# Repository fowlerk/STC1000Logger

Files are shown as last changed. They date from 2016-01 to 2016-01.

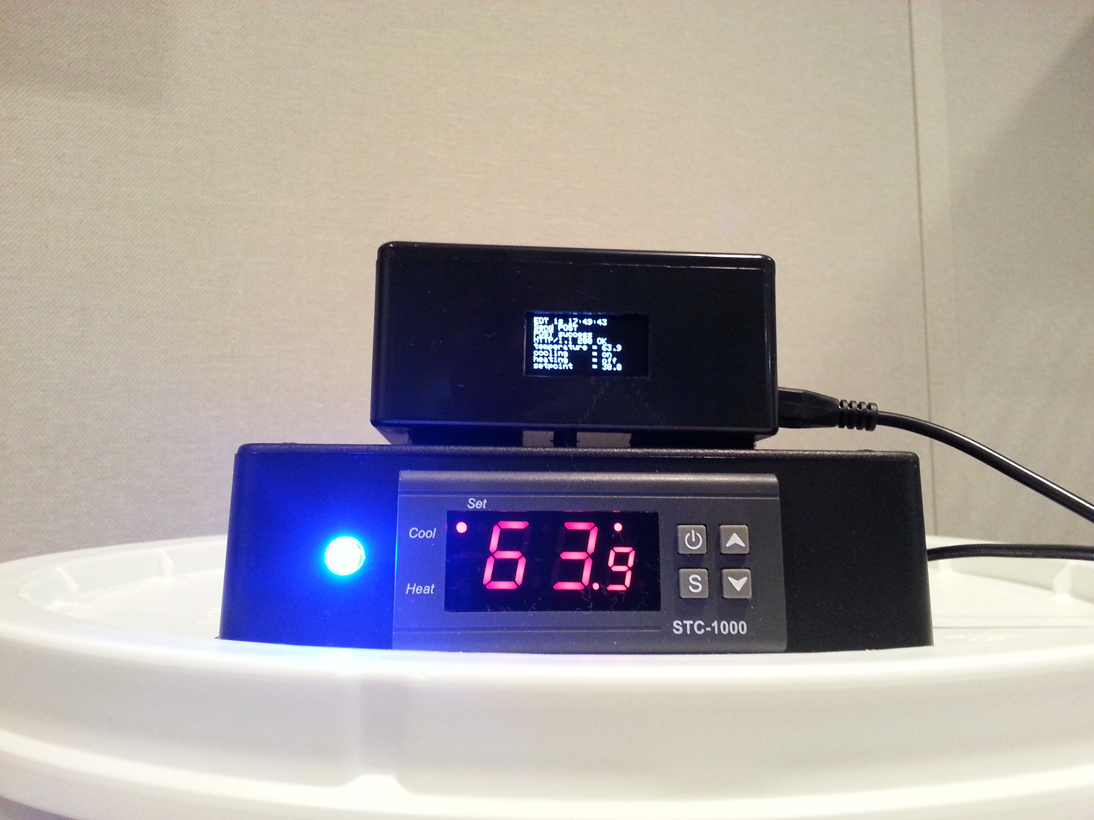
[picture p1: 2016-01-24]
20160124_175003.jpg

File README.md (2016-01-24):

##STC-1000+ Wireless Data Logger

This project creates a wireless data logger to interface with the STC-1000+ dual-stage temperature controller, running the (great!) communications firmware designed and written by Mats Staffansson.  Let me take the opportunity to thank Mats for all of his great contributions to the homebrewing community through his tireless efforts in creating the various versions of the STC firmware.  Without him, none of this would have been possible.

This code retrieves key data from the STC-1000 on a periodic basis as defined in the code.  The parameters retrieved and logged are:  setpoint, current probe temperature, status of the cooling and heating relays, run-mode (profile or thermostat), step (for profile), and duration hours.

This version of the project was written specifically for the Adafruit Huzzah ESP-8266 package.  Through the various iterations of this effort, I've used other versions of the ESP (notably the Cactus Micro version initially), but settled on this one because of its stability, breakout of most of the GPIO pins, and huge (4M) flash size.  This has allowed be to include support for much more extensive error-checking and correction in the code, along with support for an external display (an SSD1306 based OLED) to monitor what’s going on in real time.

## Background

Being a homebrewer for several years now, I initially became interested in temperature control for my fermentations when I wanted to tackle my first lager.  I stumbled on Mats thread on the STC, and was impressed with what he'd done.  After purchasing and using a controller with his firmware a couple of times, I wanted to be able to log my fermentation activity in order to help improve my future attempts.  Mats inspired me in some of his discussions on using the ESP in order to do this, though I eventually decided to take a somewhat different route than the base ESP-01 using Sming he’d mentioned.  I ran across the Cactus Micro package from April Brother and decided to use it for my first attempt.  It combines the Atmel ATmega32U4 MCU and the ESP-8266 WiFi SOC.  Though I managed to put together a version that ran (fairly) well on this package, I found it somewhat unreliable in that it would hang every few days to hours.  A simple restart would get it running again, but I was frustrated by not knowing what was going on in real time, and more so, by not having enough flash to be able to add what I considered to be adequate error checking and correction to the code.  (This may have been as much a reflection of my barely-adequate coding or electronics abilities, but I tire quickly of trying to optimize code to fit in smaller flash.)

So, I began looking around for better hardware solutions that were still relatively inexpensive.  I decided to try the Adafruit Huzzah ESP-8266 as an alternative.  It didn't take long to fall in love with this package.  It seems to be much more stable, has tons of flash (4M), breaks out all of the GPIO’s for use, and supports nice additions like h/w SPI (used for the OLED display).

## Getting it Running

### The Data Stream

Though there are a number of free data-streaming services available on-line, I decided to first try one provided by SparkFun at data.sparkfun.com.  It is a public implementation of a Phant server, though the code is freely available to download and run your own instance if you desire.  For my initial attempt, I didn't mind putting this up so that it was available to the public, but was very interested in being able to run my own instance in the future.  In order to get started, you must first go to data.sparkfun.com and set up a data stream for logging your data.  It is quite simple and fast to do so, just be sure to create fieldnames that match exactly the names used in the code.  Also be sure to note the public and private keys, as these must be entered in the code to connect to the stream once created.

### The OLED Library

One of the downsides for working with the ESP-8266 is that some of the libraries still have not been ported to this platform for the Arduino IDE (which is what I used for my efforts).  When I decided to use the SSD1306 controller-based OLED, I found this to be a minor stumbling block initially, but eventually discovered someone had been able to make minor edits to the Adafruit library to support this.  It essentially amounts to a couple of trivial edits (additions) to one of the library files (Adafruit_GFX.cpp), and is described here:  [https://github.com/somhi/ESP_SSD1306](https://github.com/somhi/ESP_SSD1306)

I saved the edits to a copy of the original library called ESP_SSD1306 so that I could use either the original or the modified one going forward.  (Thanks to SOMHI for his efforts on this, and Adafruit / LadyAda for their work in creating the original library!)

Note that I used a 4-wire SPI version of the OLED, though I've read others have gotten the I2C version working as well.  I’ve used both 1.3 inch and 0.96 inch versions of these successfully.

Final note on the OLED...I added this strictly to have a local display of what was happening throughout the logging process as a realtime monitor.  It is strictly optional and the logger will work fine without this connected (though you'll be a little blind about what’s going on unless you have a serial monitor connected).

### NTP Server

One of the later enhancements I made to the original code was to connect to an NTP server to be able display the time on the OLED periodically.  This is displayed on line 1 in a non-scrolling region of the display so that it is always present and updated (well, assuming connection to the server is successful anyway!)  The current version of the code is hard-coded for Eastern Daylight Time (offset of -5 hours from GMT).  This must currently be edited manually, as I've not added code to automatically configure this or calculate daylight savings time (yet).

### Wiring Diagram

I've included a Fritzing diagram of the wiring to the Huzzah to help in connecting the various components.  Keep in mind that this is my first attempt at using Fritzing, and combined with my barely-adequate electronics knowledge, well, you get what you pay for here.

Note that the project is powered externally (not from the STC power supply), using a USB 5V supply.  I've included a Shottky (bat85)  diode to keep the STC from attempting to power the Huzzah.  I’ve also added a couple of resistors (7.5K and 3.9K ohm) in a voltage-divider to drop the 5V signal from the STC to 3.3V range for the Huzzah.  Finally, I’ve added a pull-down 10K resistor for the *ICSPCLK *line as Mats recommended in his documentation.

The only connections required to the STC are VCC, GND, and ICSPCLK, as shown in the diagram.

### Futures

One of my satisfactions in building something like this, especially when writing code I've found, is that I’m never quite fully done -- I’m always finding something else I’d like to add to make it better.  That said, I’ve been looking at building in a web-configurator in order to configure the various settings (network settings, NTP server, timezone, Phant settings, etc.)  I’d also like it to be able to check for DST automatically.  Stay tuned...

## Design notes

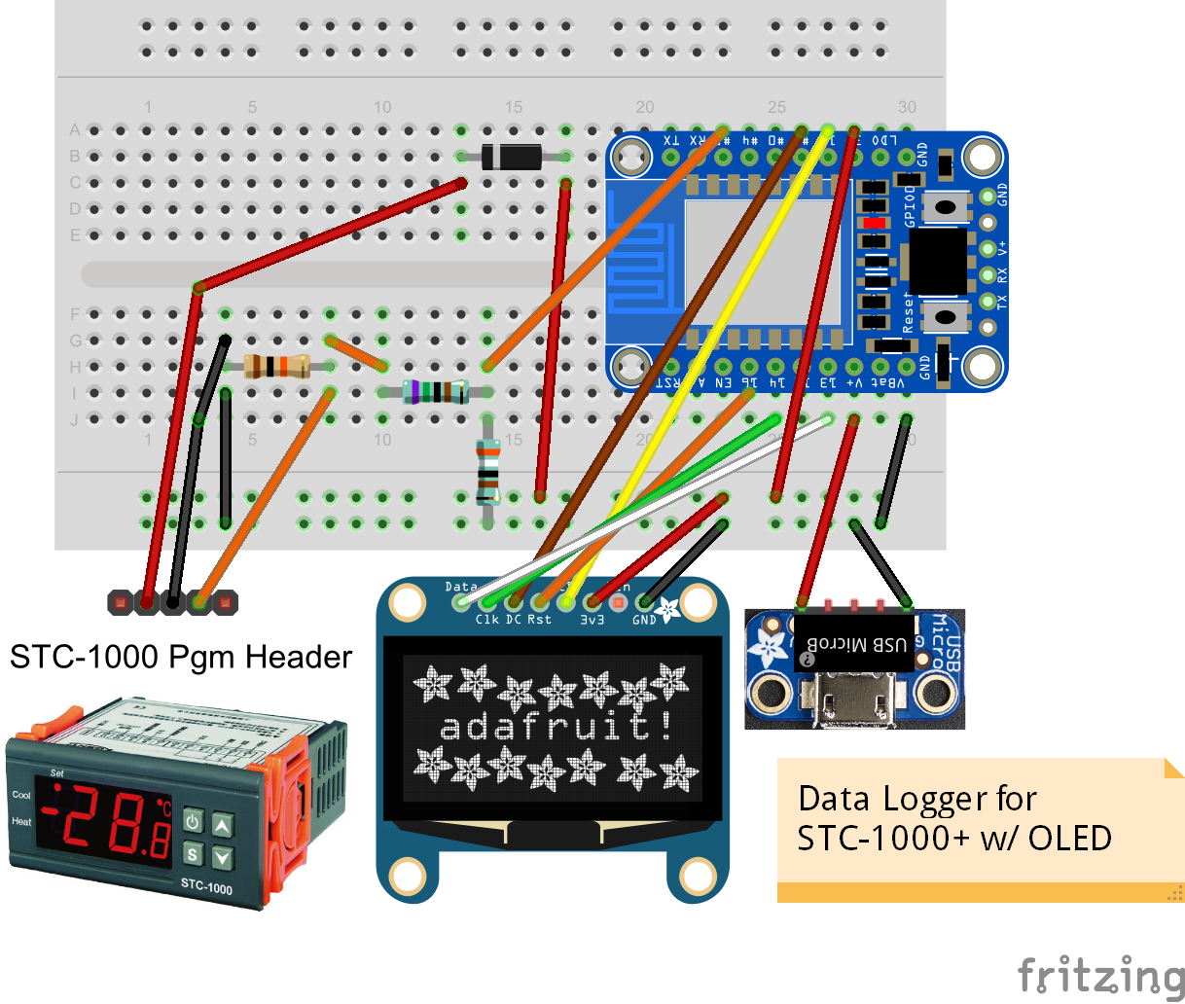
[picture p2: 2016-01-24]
STC-1000 ESP8266 DataLogger Final 151221.png

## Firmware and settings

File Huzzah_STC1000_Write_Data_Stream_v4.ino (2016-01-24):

/*
 * This routine will collect key information from the attached STC-1000+
 * on a frequency as specified herein, and write this information to a
 * SparkFun (phant) datastream.  This version was written for the Adafruit
 * Huzzah ESP-8266, and utilizes the WiFi library for communications with
 * the ESP.  It also supports an attached OLED to display status information
 * during operation, along with output to the serial monitor.
 * 
 * This variation of the original uses the Phant library to build a request 
 * and post the data to the datastream (vs. the original HTTP GET).  It also 
 * includes the enhancements made to get the NTP time periodically and 
 * display it to the first line of the OLED (no-scroll region) so that it is
 * constantly displayed.  See README file for information on (small) changes 
 * made to the Adafruit SSD1306 OLED library to support the ESP8266 h/w SPI.
 * 
 *    Modified by DK Fowler...11-Dec-2015
 *    Extensions to the original code by Mats Staffansson by
 *    Keith Fowler...01-Dec-2015.
 *    
 *    Copyright 2016 Keith Fowler
 *    
 **** Mats original comments follow ***
 * 
 * STC1000+, improved firmware and Arduino based firmware uploader for the STC-1000 dual stage thermostat.
 * 
 *
 * Copyright 2014 Mats Staffansson
 *
 * This file is part of STC1000+.
 *
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
 */
#include <SPI.h>
#include <Wire.h>
#include <ESP8266WiFi.h>
#include <WiFiUdp.h>
#include <Phant.h>

#include <Adafruit_GFX.h>
#include <ESP_SSD1306.h>

// Define pins to use hardware SPI for OLED display
#define OLED_DC     2
#define OLED_CS     15
#define OLED_RESET  16
ESP_SSD1306 display(OLED_DC, OLED_RESET, OLED_CS);

#define LOGO16_GLCD_HEIGHT 16 
#define LOGO16_GLCD_WIDTH  16 
static const unsigned char PROGMEM logo16_glcd_bmp[] =
{ B00000000, B11000000,
  B00000001, B11000000,
  B00000001, B11000000,
  B00000011, B11100000,
  B11110011, B11100000,
  B11111110, B11111000,
  B01111110, B11111111,
  B00110011, B10011111,
  B00011111, B11111100,
  B00001101, B01110000,
  B00011011, B10100000,
  B00111111, B11100000,
  B00111111, B11110000,
  B01111100, B11110000,
  B01110000, B01110000,
  B00000000, B00110000 };

#if (SSD1306_LCDHEIGHT != 64)
#error("Height incorrect, please fix Adafruit_SSD1306.h!");
#endif

//  Define display size in lines, characters.  Change
//  for different display sizes (or fonts used).
#define DISPLAY_LINES 8
#define DISPLAY_WIDTH_CHARS 21
byte displayLineIndex = 0;
String OLEDdisplayBuff[DISPLAY_LINES];

int status = WL_IDLE_STATUS;

//********* Change the following values for a different SSID or
//********* password.
char ssid[] = "SSID";               // your network SSID (name)
char pass[] = "SSIDpassword";       // your network password

// Initialize the Wifi client library
WiFiClient client;
// Set the IP address for the client
//********* Change the following values to configure a different
//********* client IP address, gateway, or subnet mask.
IPAddress clientIP(192, 168, 0, 5);
IPAddress clientGateway(192,168,0,1);
IPAddress clientSubnet(255,255,255,0);

////////////////////////////
// Sparkfun (Phant) Stuff //
////////////////////////////
//********* Create the Sparkfun datastream before first use following
//********* directions at https://data.sparkfun.com/.  For this code,
//********* the fieldnames must match the names in fieldNames exactly
//********* as listed below.
const byte NUM_FIELDS = 7;
const String fieldNames[NUM_FIELDS] = {
  "temperature","cooling","heating","setpoint","runmode","step","duration" };

String fieldData[NUM_FIELDS];
String displayField;

// Sparkfun (Phant) server address for posting data to stream.
//********* Change the following public and private key values to post to 
//********* your own Phant datastream once created.  Alternatively, you
//********* can specify your own local Phant server.
char server[] = "data.sparkfun.com";
const String publicKey = "";
const String privateKey = "";
const char POSTGood[16]="HTTP/1.1 200 OK";
Phant phant(server, publicKey, privateKey);   // Initialize the Phant datastream 
  
// Setup NTP relevant parameters

unsigned int localPort = 2390;        // local port to listen for UDP packets
// IPAddress timeServer(129, 6, 15, 28);  // time.nist.gov NTP server
IPAddress timeServer(24, 56, 178, 140);   // www.nist.gov NTP server, Ft. Collins, CO
const int NTP_PACKET_SIZE = 48;       // NTP time stamp is in the first 48 bytes of the message
byte packetBuffer[ NTP_PACKET_SIZE];  //buffer to hold incoming and outgoing packets

// A UDP instance to let us send and receive packets over UDP

WiFiUDP Udp;
  
long nextTime = 0;      //next time in millis that the read cycle will fire

//period between posts, set at 30 seconds
#define DELAY_PERIOD 30000

// Period between NTP update calls, displayed on OLED and on serial 
// monitor.
#define DELAY_NTP_UPDATE 30000
long nextNTPTime = 0;   // next time in millis that NTP update will fire
boolean NTPUpdate = false;

#define DEBUG 1

#define	COM_PIN			5	// ICSPCLK, used for the half-duplex comm with STC-1000

#define COM_READ_EEPROM		0x20
#define COM_WRITE_EEPROM	0xE0
#define COM_READ_TEMP		0x01
#define COM_READ_COOLING	0x02
#define COM_READ_HEATING	0x03
#define COM_ACK			0x9A
#define COM_NACK		0x66

void write_bit(unsigned const char data){
	pinMode(COM_PIN, OUTPUT);
	digitalWrite(COM_PIN, HIGH);
	delayMicroseconds(7);
	if(!data){
		pinMode(COM_PIN, INPUT);
		digitalWrite(COM_PIN, LOW);
	}
	delayMicroseconds(400);
	pinMode(COM_PIN, INPUT);
	digitalWrite(COM_PIN, LOW);
	delayMicroseconds(100);
}

unsigned char read_bit(){
	unsigned char data;

	pinMode(COM_PIN, OUTPUT);
	digitalWrite(COM_PIN, HIGH);
	delayMicroseconds(7);
	pinMode(COM_PIN, INPUT);
	digitalWrite(COM_PIN, LOW);
	delayMicroseconds(200);
	data = digitalRead(COM_PIN);
	delayMicroseconds(300);

	return data;
}

void write_byte(unsigned const char data){
	unsigned char i;
	
	for(i=0;i<8;i++){
		write_bit(((data << i) & 0x80));
	}
	delayMicroseconds(500);
}

unsigned char read_byte(){
	unsigned char i, data;
	
	for(i=0;i<8;i++){
		data <<= 1;
		if(read_bit()){
			data |= 1;
		}
	}
	delayMicroseconds(500);

	return data;
}


bool write_eeprom(const unsigned char address, unsigned const int value){
	unsigned char ack;
	write_byte(COM_WRITE_EEPROM);
	write_byte(address);
	write_byte(((unsigned char)(value >> 8)));
	write_byte((unsigned char)value);
	write_byte(COM_WRITE_EEPROM ^ address ^ ((unsigned char)(value >> 8)) ^ ((unsigned char)value));
	delay(6); // Longer delay needed here for EEPROM write to finish, but must be shorter than 10ms
	ack = read_byte();
	return ack == COM_ACK; 
}

bool read_eeprom(const unsigned char address, int *value){
	unsigned char xorsum;
	unsigned char ack;
        unsigned int data;

//        Serial.println("Read EEPROM called...");    // Debug
        
	write_byte(COM_READ_EEPROM);
	write_byte(address);
	data = read_byte();
	data = (data << 8) | read_byte();
	xorsum = read_byte();
        ack = read_byte();
	if(ack == COM_ACK && xorsum == (COM_READ_EEPROM ^ address ^ ((unsigned char)(data >> 8)) ^ ((unsigned char)data))){
	        *value = (int)data;
//                Serial.print("Address read = ");    // Debug
//                Serial.println(address);            // Debug
//                Serial.print("Data returned = ");   // Debug
//                Serial.println(*value);             // Debug
		return true;
	}
	return false;
}

bool read_command(unsigned char command, int *value){
	unsigned char xorsum;
	unsigned char ack;
        unsigned int data;

//        Serial.println("Read command called...");    // Debug
        
	write_byte(command);
	data = read_byte();
	data = (data << 8) | read_byte();
	xorsum = read_byte();
        ack = read_byte();
	if(ack == COM_ACK && xorsum == (command ^ ((unsigned char)(data >> 8)) ^ ((unsigned char)data))){
	        *value = (int)data;
//                Serial.print("Command = ");         // Debug
//                Serial.println(command);            // Debug
//                Serial.print("Value returned = ");  // Debug
//                Serial.println(*value);             // Debug
		return true;
	}
	return false;
}

bool read_temp(int *temperature){
	return read_command(COM_READ_TEMP, temperature); 
}

bool read_heating(int *heating){
	return read_command(COM_READ_HEATING, heating); 
}

bool read_cooling(int *cooling){
	return read_command(COM_READ_COOLING, cooling); 
}

/* End of communication implementation */

/* From here example implementation begins, this can be exchanged for your specific needs */
enum set_menu_enum {
	hysteresis,			          // hy (hysteresis)
	hysteresis2,			        // hy2 (hysteresis probe 2)
	temperature_correction,		// tc (temperature correction)
	temperature_correction2,	// tc2 (temperature correction probe 2)
	setpoint_alarm,			      // SA (setpoint alarm)
	setpoint,			            // SP (setpoint)
	step,				              // St (current running profile step)	
	duration,			            // dh (current running profile step duration in hours)
	cooling_delay,			      // cd (cooling delay minutes)
	heating_delay,			      // hd (heating delay minutes)
	ramping,			            // rP (0=disable, 1=enable ramping)
	probe2,				            // Pb (0=disable, 1=enable probe2 for regulation)
	run_mode			            // rn (0-5 run profile, 6=thermostat)
};

/* Defines for EEPROM config addresses */
#define EEADR_PROFILE_SETPOINT(profile, stp)	(((profile)*19) + ((stp)<<1))
#define EEADR_PROFILE_DURATION(profile, stp)	(EEADR_PROFILE_SETPOINT(profile, stp) + 1)
#define EEADR_SET_MENU				EEADR_PROFILE_SETPOINT(6, 0)
#define EEADR_SET_MENU_ITEM(name)		(EEADR_SET_MENU + (name))
#define EEADR_POWER_ON				127

const char menu_opt[][4] = {
	"hy",
	"hy2",
	"tc",
	"tc2",
	"SA",
	"SP",
	"St",
	"dh",
	"cd",
	"hd",
	"rP",
	"Pb2",
	"rn"
};

bool isBlank(char c){
	return c == ' ' || c == '\t';
}

bool isDigit(char c){
	return c >= '0' && c <= '9';
}

bool isEOL(char c){
	return c == '\r' || c == '\n';
}

void print_temperature(int temperature){
	if(temperature < 0){
		temperature = -temperature;
		Serial.print('-');
	}
	if(temperature >= 1000){
		temperature /= 10;
		Serial.println(temperature);
	} else {
		Serial.print(temperature/10);
		Serial.print('.');
		Serial.println(temperature%10);
	}
}

String format_temperature(int temperature){
        String strTemperature="";
  	if(temperature < 0){
		strTemperature = "-" + String(temperature);
	}
	if(temperature >= 1000){
		strTemperature = String(temperature/10.0,1);
	} else {
                strTemperature = String(temperature/10.0,1);
	}
        return strTemperature;
}

void print_config_value(unsigned char address, int value){
	if(address < EEADR_SET_MENU){
		unsigned char profile=0;
		while(address >= 19){
			address-=19;
			profile++;
		}
		if(address & 1){
			Serial.print("dh");
		} else {
			Serial.print("SP");
		}
		Serial.print(profile);
		Serial.print(address >> 1);
		Serial.print('=');
		if(address & 1){
			Serial.println(value);
		} else {
			print_temperature(value);
		}
	} else {
		Serial.print(menu_opt[address-EEADR_SET_MENU]);
		Serial.print('=');
		if(address == EEADR_SET_MENU_ITEM(run_mode)){
			if(value >= 0 && value <= 5){
				Serial.print("Pr");
				Serial.println(value);
			} else {
				Serial.println("th");
			}
		} else if(address <= EEADR_SET_MENU_ITEM(setpoint)){
			print_temperature(value);
		} else {
			Serial.println(value);
		}
	}
}

unsigned char parse_temperature(const char *str, int *temperature){
	unsigned char i=0;
	bool neg = false;

	if(str[i] == '-'){
		neg = true;
		i++;
	}

	if(!isDigit(str[i])){
		return 0;
	}

	*temperature = 0;
	while(isDigit(str[i])){
		*temperature = *temperature * 10 + (str[i] - '0');
		i++;
	}
	*temperature *= 10;
	if(str[i] == '.'){
		i++;
		if(isDigit(str[i])){
			*temperature += (str[i] - '0');
			i++;
		} else {
			return 0;
		} 
	}

	if(neg){
		*temperature = -(*temperature);
	}

	return i;
} 

unsigned char parse_address(const char *cmd, unsigned char *addr){
	char i;	

	if(!strncmp("SP", cmd, 2)){
		if(isDigit(cmd[2]) && isDigit(cmd[3]) && cmd[2] < '6'){
			*addr = EEADR_PROFILE_SETPOINT(cmd[2]-'0', cmd[3]-'0');
			return 4;
		}
	}

	if(!strncmp("dh", cmd, 2)){
		if(isDigit(cmd[2]) && isDigit(cmd[3]) && cmd[2] < '6' && cmd[3] < '9'){
			*addr = EEADR_PROFILE_DURATION(cmd[2]-'0', cmd[3]-'0');
			return 4;
		}
	}

	for(i=0; i<(sizeof(menu_opt)/sizeof(menu_opt[0])); i++){
		unsigned char len = strlen(menu_opt[i]);
		if(!strncmp(cmd, &menu_opt[i][0], len) && (isBlank(cmd[len]) || isEOL(cmd[len]))){
			*addr = EEADR_SET_MENU + i;
			return strlen(menu_opt[i]);
		}
	}

	*addr = 0;
	for(i=0; i<30; i++){
		if(isBlank(cmd[i]) || isEOL(cmd[i])){
			break;
		}
		if(isDigit(cmd[i])){
			if(*addr>12){
				return 0;
			} else {
				*addr = *addr * 10 + (cmd[i] - '0');
		 	}
		} else {
			return 0;
		}
	}

	if(*addr > 127){
		return 0;
	}

	return i;
}

unsigned char parse_config_value(const char *cmd, int address, bool pretty, int *data){
	unsigned char i=0;
	bool neg=false;

	if(pretty){
		if(address < EEADR_SET_MENU){
			while(address >= 19){
				address-=19;
			}
			if((address & 1) == 0){
				return parse_temperature(cmd, data);
			}
		} else if(address <= EEADR_SET_MENU_ITEM(setpoint)){
			return parse_temperature(cmd, data);
		} else if(address == EEADR_SET_MENU_ITEM(run_mode)) {
			if(!strncmp(cmd, "Pr", 2)){
				*data = cmd[2] - '0';
				if(*data >= 0 && *data <= 5){
					return 3;
				}
			} else if(!strncmp(cmd, "th", 2)){
				*data = 6;
				return 2;
			}
			return 0;
		}
	}	

	if(cmd[i] == '-'){
		neg = true;
		i++;
	}

	if(!isDigit(cmd[i])){
		return 0;
	}

	for(*data=0; i<6; i++){
		if(!isDigit(cmd[i])){
			break;
		}
		if(isDigit(cmd[i]) && *data < 3276){
			*data = *data * 10 + (cmd[i] - '0');
		} else {
			return 0;
		}
	}

	if((neg && *data > 32768) || (!neg && *data > 32767)){
		return 0;
	}

	if(neg){
		*data = -(*data);
	}
	
	return i;
}

void parse_command(char *cmd){
	int data;

	if(cmd[0] == 't'){
		if(!isEOL(cmd[1])){
			Serial.println("?Syntax error");
			return;
		}
		if(read_temp(&data)){
			Serial.print("Temperature=");
			print_temperature(data);
		} else {
			Serial.println("?Communication error");
		}
	} else if(cmd[0] == 'h'){
		if(!isEOL(cmd[1])){
			Serial.println("?Syntax error");
			return;
		}
		if(read_heating(&data)){
			Serial.print("Heating=");
			Serial.println(data ? "on" : "off");
		} else {
			Serial.println("?Communication error");
		}
	} else if(cmd[0] == 'c'){
		if(!isEOL(cmd[1])){
			Serial.println("?Syntax error");
			return;
		}
		if(read_cooling(&data)){
			Serial.print("Cooling=");
			Serial.println(data ? "on" : "off");
		} else {
			Serial.println("?Communication error");
		}
	} else if(cmd[0] == 'r' || cmd[0] == 'w') {
		unsigned char address=0;
		unsigned char i=0, j;
		bool neg = false;

		if(!isBlank(cmd[1])){
			Serial.println("?Syntax error");
			return;
		}

		j = parse_address(&cmd[2], &address);
		i+=j+2;

		if(j==0){
			Serial.println("?Syntax error");
			return;
		}

		if(cmd[0] == 'r'){
			if(!isEOL(cmd[i])){
				Serial.println("?Syntax error");
				return;
			}
			if(read_eeprom(address, &data)){
				if(isDigit(cmd[2])){
					Serial.print("EEPROM[");
					Serial.print(address);
					Serial.print("]=");
					Serial.println(data);
				} else {
					print_config_value(address, data);
				}
			} else {
				Serial.println("?Communication error");
			}
			return;
		}

		if(!isBlank(cmd[i])){
			Serial.println("?Syntax error");
			return;
		}
		i++;

		j = parse_config_value(&cmd[i], address, !isDigit(cmd[2]), &data);
		i += j;
		if(j == 0){
			Serial.println("?Syntax error");
			return;
		} else {
			if(!isEOL(cmd[i])){
				Serial.println("?Syntax error");
				return;
			}
			if(write_eeprom(address, data)){
				Serial.println("Ok");
			} else {
				Serial.println("?Communication error");
			}
		}
	}
}
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
void loop() {

  char serialbuffer[100];//serial buffer for request command
//  char myserialbuffer[512];//serial buffer for ESP8266
  byte padLen;
  int data, rn, St, dh;
  String strTemperature;
  String strCooling;
  String strHeating;
  String strSP;
  String strRn;
  String strSt;
  String strDh;

  #define COM_READ_SP	0x77
  #define COM_READ_rn	0x7E
  #define COM_READ_rP 0x7C
  #define COM_READ_St	0x78
  #define COM_READ_dh	0x79
   
  byte cooling, heating, commErr, commErrThisPass;

  static char cmd[32], rxchar=' ';
  static unsigned char index=0; 	

  if(Serial.available() > 0){
      char c = Serial.read();
      if(!(isBlank(rxchar) && isBlank(c))){
	      cmd[index] = c;
	      rxchar = c;
	      index++;
      }

      if(index>=31 || isEOL(rxchar)){
	      cmd[index] = '\0';
	      parse_command(cmd);
	      index = 0;
	      rxchar = ' ';
      }
  }

  if (status != WL_CONNECTED) {
    connectWiFi();
  }  

  if(nextTime<millis()){
    Serial.println();
    Serial.print("Timer reset: ");
    Serial.println(nextTime);

    //reset timer
    nextTime = millis() + DELAY_PERIOD;

//  Flush the serial receive buffer in preparation for further processing...

    clearRx();
    
//   Read data (current temperature, heating / cooling relays, setpoint, running profile, step, and duration hours)

    commErr=0;

//  Try up to 5 times to get a valid reading; otherwise flag as an error this pass and continue.

    for (int i = 0; i < 5; i++) {
      if(read_temp(&data)){
        strTemperature=format_temperature(data);
        Serial.print("Temperature\t= ");
        Serial.println(strTemperature);
        commErrThisPass=0;
        break;
      } else {
        commErrThisPass=1;
        strTemperature="err";
        Serial.print("?Communication error for attempt ");
        Serial.println(i+1);
      }
      delay(500);
    }
    fieldData[0] = strTemperature;
    if(commErrThisPass) {commErr=1;}
    
    for (int i = 0; i < 5; i++) {
      if(read_cooling(&data)){
        cooling=data;
        strCooling=(cooling ? "on" : "off");
        Serial.print("Cooling\t\t= ");
        Serial.println(data ? "on" : "off");
        commErrThisPass=0;
        break;
      } else {
        commErrThisPass=1;
        strCooling="err";
        Serial.print("?Communication error for attempt ");
        Serial.println(i+1);
      }
      delay(500);
    }
    fieldData[1] = strCooling;
    if(commErrThisPass) {commErr=1;}

    for (int i = 0; i < 5; i++) {
      if(read_heating(&data)){
        heating=data;
        strHeating=(heating ? "on" : "off");
        Serial.print("Heating\t\t= ");
        Serial.println(data ? "on" : "off");
        commErrThisPass=0;
        break;
      } else {
        commErrThisPass=1;
        strHeating="err";
        Serial.print("?Communication error for attempt ");
        Serial.println(i+1);
      }
      delay(500);
    }
    fieldData[2] = strHeating;
    if(commErrThisPass) {commErr=1;}

    for (int i = 0; i < 5; i++) {
      if(read_eeprom(COM_READ_SP, &data)){
        strSP=format_temperature(data);
        Serial.print("SP\t\t= ");
        Serial.println(strSP);
        commErrThisPass=0;
        break;
      } else {
        commErrThisPass=1;
        Serial.print("?Communication error for attempt ");
        Serial.println(i+1);
        strSP="err";
      }
      delay(500);
    }
    fieldData[3] = strSP;
    if(commErrThisPass) {commErr=1;}

    for (int i = 0; i < 5; i++) {
      if(read_eeprom(COM_READ_rn, &data)){
        rn=data;
        if ((rn >= 0) && (rn <=5)) {
          strRn="Pr" + String(rn);
        } else {
          strRn="th";
        }
        Serial.print("rn\t\t= ");
        Serial.println(strRn);
        commErrThisPass=0;
        break;
      } else {
        commErrThisPass=1;
        Serial.print("?Communication error for attempt ");
        Serial.println(i+1);
        strRn="err";
      }
      delay(500);
    }
    fieldData[4] = strRn;
    if(commErrThisPass) {commErr=1;}

    for (int i = 0; i < 5; i++) {
      if(read_eeprom(COM_READ_St, &data)){
        St=data;
        strSt=String(St);
        Serial.print("St\t\t= ");
        Serial.println(strSt);
        commErrThisPass=0;
        break;
      } else {
        commErrThisPass=1;
        Serial.print("?Communication error for attempt ");
        Serial.println(i+1);
        strSt="99";    // Flag for an error occurred
      }
      delay(500);
    }
    fieldData[5] = strSt;
    if(commErrThisPass) {commErr=1;}

    for (int i = 0; i < 5; i++) {
      if(read_eeprom(COM_READ_dh, &data)){
        dh=data;
        strDh=String(dh);
        Serial.print("dh\t\t= ");
        Serial.println(strDh);
        commErrThisPass=0;
        break;
      } else {
        commErrThisPass=1;
        Serial.print("?Communication error for attempt ");
        Serial.println(i+1);
        strDh="99";    // Flag for an error occurred
      }
      delay(500);
    }
    fieldData[6] = strDh;
    if(commErrThisPass) {commErr=1;}

//  If all of the data is good, send data to SparkFun stream (temperature, set point, cooling, heating, run mode, step, duration hours)
    if (!commErr) {
      //  Display the data on the OLED...pad it with spaces to align.
      for (byte i=0; i<NUM_FIELDS; i++) {
        padLen = 11 - fieldNames[i].length();
        displayField=fieldNames[i];
        for (byte ii=0; ii<padLen; ii++) {
          displayField = displayField + " ";
        }
        displayOLED(displayField + " = " + fieldData[i]);
      }
      postHTTP();
    } else {
      Serial.println("Skipped logging to data stream due to comm error this pass...");
    }
    delay(1000);
  }
  
  if(nextNTPTime<millis()){
    Serial.println();
    Serial.print("NTP timer reset: ");
    Serial.println(nextNTPTime);

    // Reset NTP timer
    nextNTPTime = millis() + DELAY_NTP_UPDATE;

    // Update NTP time on display an in serial console.
    getNTPTime();
  }
}

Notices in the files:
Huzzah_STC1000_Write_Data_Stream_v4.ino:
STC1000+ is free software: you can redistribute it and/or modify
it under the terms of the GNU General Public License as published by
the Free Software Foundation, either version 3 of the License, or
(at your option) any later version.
